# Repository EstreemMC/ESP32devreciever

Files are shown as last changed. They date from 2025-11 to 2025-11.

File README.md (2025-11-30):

# ESP32devreciever
An addon for my gamecube portable to enable wireless communications. The reciever will work for wireless gamecube controller(s) as well as wireless code upload for macros and inputs from a computer.

For the receiver, data integrity is vital for a solid wireless connection. I'd also like to be able to store macro files on the receiver, which should be activated by a hotkey or button combination. Connection should be seamless and integrated. Thankfully, no voltage regulators or power supplies are needed; however, to make flashing easier, I will incorporate a low level voltage regulator for the USB-C spec. On the portable itself, VIN will be supplied by the RVL-PMS-2, which has 3v3 out.

This should take little to no space. Minimizing outputs(only 17IO and 1 PWM in) should only require a maximum of 20 pins, 10 on each side of the motherboard(including 1 for 3.3v and 1 for ground. No debug to minimize space requirements. I need to satisfy the IO requirements for most of these pins. 

Utilizing the ESP32-WROOM-S3-N16 should be perfect; high flash memory, integrated SOC, and all the functionality of an ESP32. With that, I'll begin the schematic.

Finished developing the schematic, most components were brought over from the transmitter made earlier. Working from a new computer so I had to re download and modify footprint libraries. Smaller voltage regulator, limited my GPIO output pins severely so I could fit everything with just 20 jumper pins. PCB routing is going to be a pin, since I'll be using a 2layer board this time and need a much more compact PCB.

For some reason, this PCB layout and routing was infinitely more difficult than my last. I can attribute most of the difficulties to the dramatically smaller size and the lack of 4 layers, with me settling for just two. overall, I'm really happy with the way it turned out and I can't wait to implement it on my actual console!







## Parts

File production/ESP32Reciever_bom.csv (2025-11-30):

Designator | Footprint | Quantity | Value | LCSC Part #
C5 | 0603 | 1 | 10u
C6 | 0603 | 1 | 22u
C7 | 0603 | 1 | 1uF
C8, C9 | 0603 | 2 | 100n
D1, D2 | 0603 | 2 | LED
J2, J3 | PinHeader_1x10_P2.54mm_Vertical | 2 | Conn_01x10_Pin
J4 | HRO_TYPE-C-31-M-12 | 1 | TYPE-C-31-M-12
R1, R2, R3, R4, R5 | 0603 | 5 | 5.1kΩ | C23186
SW1, SW2 | SW_SPST_B3S-1100 | 2 | SW_Push
U1 | SOT-223-3_TabPin2 | 1 | LD1117S33TR_SOT223
U2 | ESP32-S3-WROOM-1 | 1 | ESP32-S3-WROOM-1

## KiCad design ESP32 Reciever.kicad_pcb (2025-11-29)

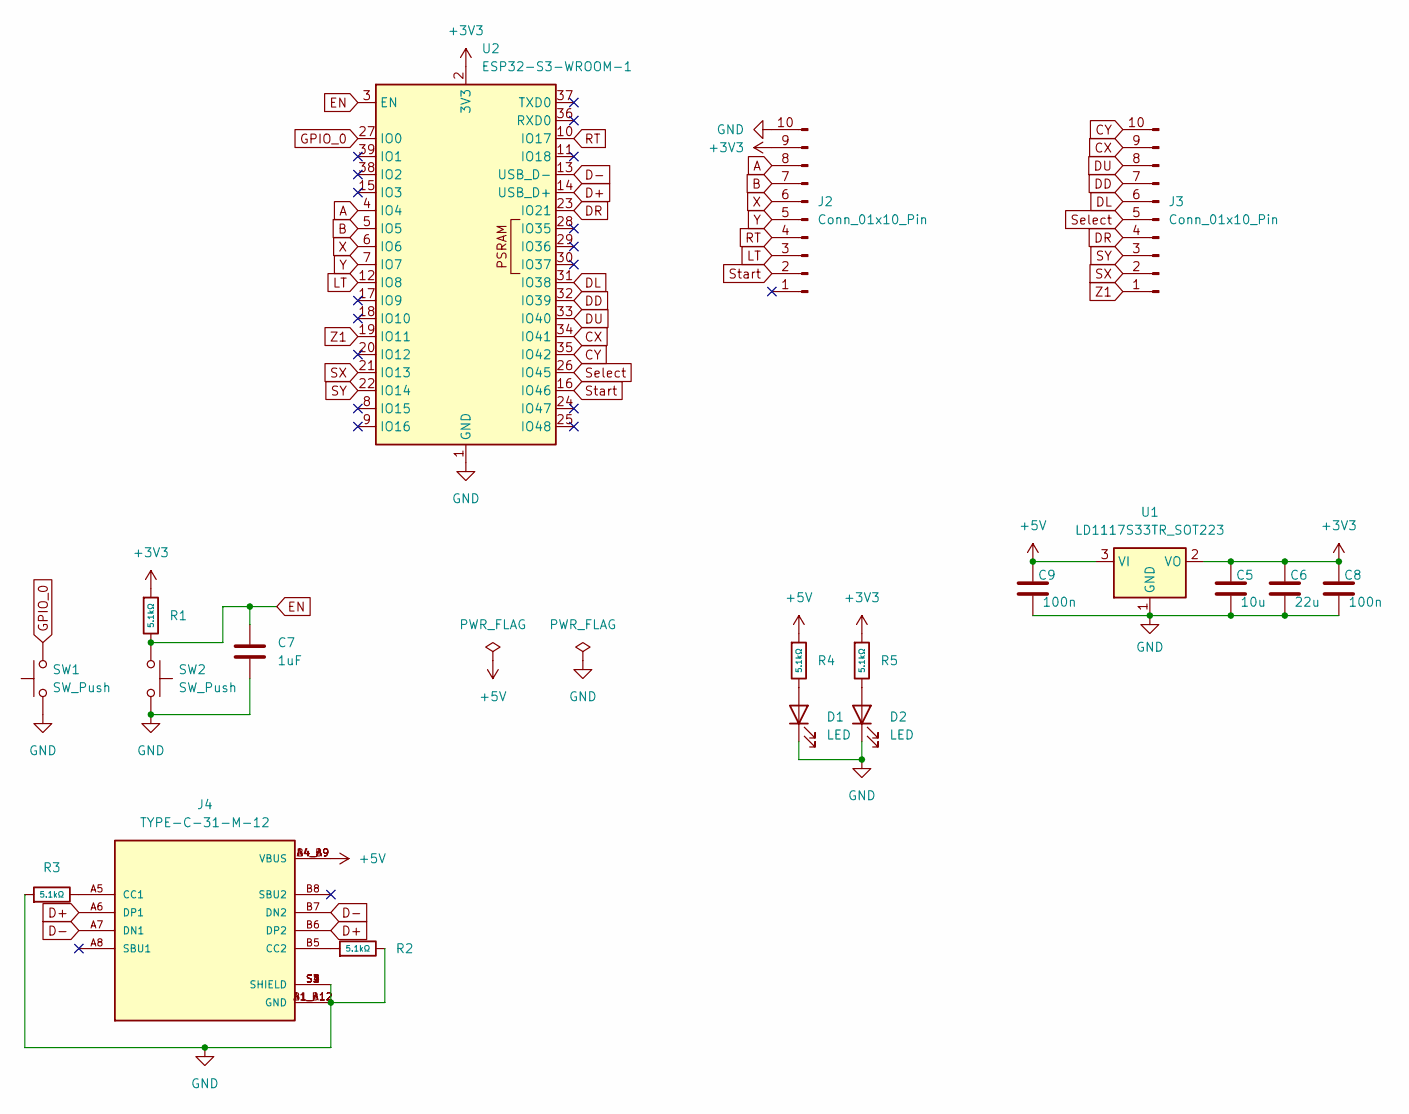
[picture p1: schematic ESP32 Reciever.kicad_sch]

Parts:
C5: 10u; C_0603_1608Metric
C6: 22u; C_0603_1608Metric
C7: 1uF; C_0603_1608Metric
C8, C9: 100n; C_0603_1608Metric
D1, D2: LED; LED_0603_1608Metric
J2, J3: Conn_01x10_Pin; PinHeader_1x10_P2.54mm_Vertical
J4: TYPE-C-31-M-12; HRO_TYPE-C-31-M-12; PARTREV 2020.12.08
R1, R2, R3, R4, R5: 5.1kΩ; C_0603_1608Metric; Overload Voltage (Max) 75V; Tolerance ±1%; Part 0603WAF5101T5E; LCSC C23186
SW1, SW2: SW_Push; SW_SPST_B3S-1100
U1: LD1117S33TR_SOT223; SOT-223-3_TabPin2
U2: ESP32-S3-WROOM-1

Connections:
+3V3: C5.1, C6.1, C8.1, J2.9, R1.1, R5.1, U1.2 (VO), U2.2 (3V3)
+5V: C9.1, J4.A4_B9 (VBUS), J4.B4_A9 (VBUS), R4.1, U1.3 (VI)
A: J2.8, U2.4 (IO4)
B: J2.7, U2.5 (IO5)
CX: J3.9, U2.34 (IO41)
CY: J3.10, U2.35 (IO42)
D+: J4.A6 (DP1), J4.B6 (DP2), U2.14 (USB_D+)
D-: J4.A7 (DN1), J4.B7 (DN2), U2.13 (USB_D-)
DD: J3.7, U2.32 (IO39)
DL: J3.6, U2.31 (IO38)
DR: J3.4, U2.23 (IO21)
DU: J3.8, U2.33 (IO40)
EN: C7.2, R1.2, SW2.1, U2.3 (EN)
GND: C5.2, C6.2, C7.1, C8.2, C9.2, D1.1 (K), D2.1 (K), J2.10, J4.A1_B12 (GND), J4.B1_A12 (GND), J4.S1 (SHIELD), J4.S2 (SHIELD), J4.S3 (SHIELD), J4.S4 (SHIELD), R2.2, R3.1, SW1.1, SW2.2, U1.1 (GND), U2.1 (GND), U2.40 (GND), U2.41 (GND)
GPIO_0: SW1.2, U2.27 (IO0)
LT: J2.3, U2.12 (IO8)
unnamed: D1.2 (A), R4.2
unnamed: D2.2 (A), R5.2
unnamed: J4.A5 (CC1), R3.2
unnamed: J4.B5 (CC2), R2.1
RT: J2.4, U2.10 (IO17)
SX: J3.2, U2.21 (IO13)
SY: J3.3, U2.22 (IO14)
Select: J3.5, U2.26 (IO45)
Start: J2.2, U2.16 (IO46)
X: J2.6, U2.6 (IO6)
Y: J2.5, U2.7 (IO7)
Z1: J3.1, U2.19 (IO11)

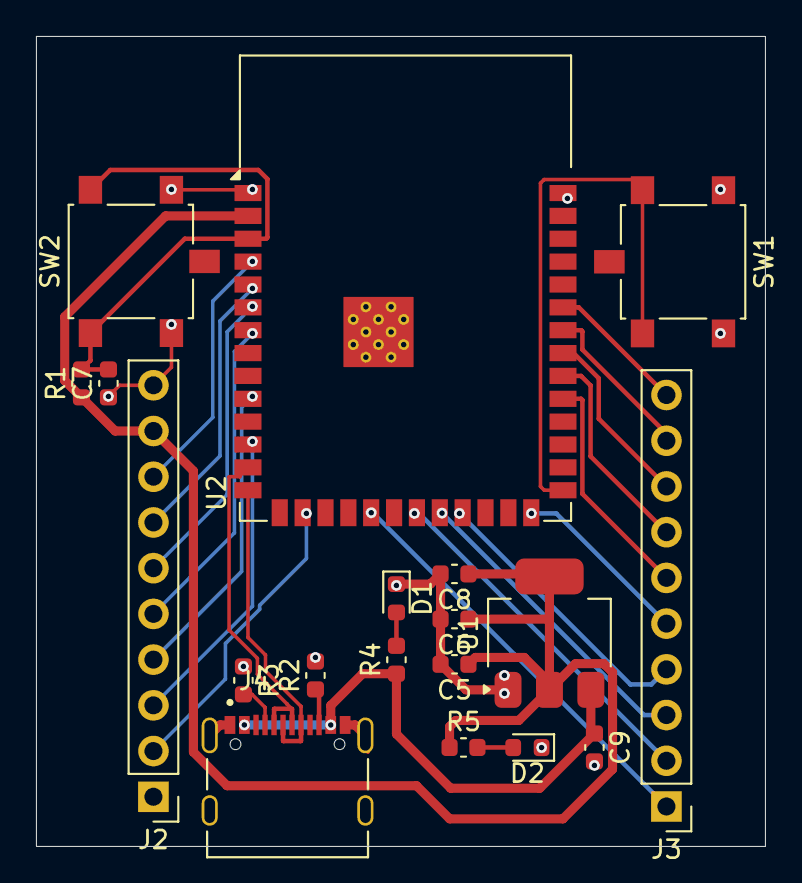
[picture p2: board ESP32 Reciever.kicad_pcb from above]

Board: 4 copper layers, 40.5 x 45.0 mm, 19 parts (0 on the bottom side), 28 nets.
